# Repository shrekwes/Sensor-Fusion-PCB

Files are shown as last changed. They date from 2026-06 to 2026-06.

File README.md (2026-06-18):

# PyFusion — RP2040 Sensor Fusion Board

A compact, custom-fabricated two-layer sensor fusion PCB built around the Raspberry Pi RP2040. Integrates a 6-axis IMU, 3-axis magnetometer, and barometric pressure sensor on a single board — programmable natively in MicroPython.

---

## Hardware

| Component | Part | Interface | Address |
|---|---|---|---|
| Microcontroller | RP2040 (dual-core Cortex-M0+, 133MHz) | — | — |
| IMU | IAM-20680HV (6-axis accel + gyro) | I2C1 — GP2/GP3 | 0x68 |
| Magnetometer | IIS2MDCTR (3-axis AMR) | I2C0 — GP8/GP9 | 0x1E |
| Barometer | BMP581 (pressure + temperature) | SoftI2C — GP6/GP7 | 0x46 |
| Flash | W25Q128JVS (128Mbit QuadSPI) | QSPI | — |
| Crystal | ABM8-272-T3 (12MHz) | XIN/XOUT | — |
| Regulator | NCP1117-3.3 (5V → 3.3V LDO) | — | — |

---

## PCB Design

The board is a two-layer design captured in KiCad 9.0. Layout decisions were driven primarily by the sensitivity requirements of the three MEMS sensors.

### Layer Stack

- **Top layer** — signal routing and 3.3V power polygon pour
- **Bottom layer** — continuous ground plane for low-impedance return paths and shielding, with minimal routing tracks

### Sensor Placement

**IMU (IAM-20680HV)**
Placed on a mechanically stable region of the board, away from mounting holes and connectors. Requires a solid ground plane beneath it for noise reduction — copper fill is maintained under this device. The exposed ground pad is connected to the ground plane via multiple vias.

**Magnetometer (IIS2MDCTR)**
Highly sensitive to magnetic fields from nearby copper currents. Ground plane and copper pours are cleared on both layers in the region surrounding this device. High-current traces and switching components are kept at a distance.

**Barometer (BMP581)**
Isolated from large copper regions on both layers to prevent thermal gradients and mechanical stress from influencing pressure readings.

### Key Layout Decisions

**Decoupling** — All bypass capacitors placed within 1–2mm of their associated VDD pins, with short via stubs to the ground plane, in accordance with each sensor's datasheet.

**Crystal** — ABM8-272-T3 placed as close as practical to the RP2040 XIN/XOUT pins. Load capacitors are inline. A copper pour guard ring tied to GND prevents switching-noise coupling into the oscillator.

**USB differential pair** — USBDP/USBDM routed as a 90Ω differential pair (0.8mm track width, 0.15mm gap on a 1mm substrate) per the RP2040 hardware design guide.

**GPIO header** — 23 pins expose selected RP2040 GPIO signals for external interfacing via UART, SPI, or I2C, making the board extensible rather than a closed system.

**BOOTSEL and RESET** — dedicated push-buttons for bootloader entry and manual reset.

### KiCad Footprint Note

The IAM-20680HV KiCad footprint files were not available at the time of design. The **ICM-20602** footprint was used as a drop-in substitute — the two devices share an identical package and pin layout. The assembled board uses the IAM-20680HV component on the ICM-20602 footprint without modification.

### Design Verification

Before manufacture the following checks were completed in KiCad:
- Electrical Rules Check (ERC) — no unconnected pins or conflicting power nets
- Design Rules Check (DRC) — cleared against manufacturer minimums (trace width, clearance, via drill, annular ring)
- Footprint verification — each land pattern cross-checked against the manufacturer datasheet
- Gerber preview — layer stack-up, drill file, and copper patterns confirmed

---

## Firmware

All firmware is written in MicroPython and runs directly on the RP2040. The board was developed and flashed using Thonny IDE.

### File Overview

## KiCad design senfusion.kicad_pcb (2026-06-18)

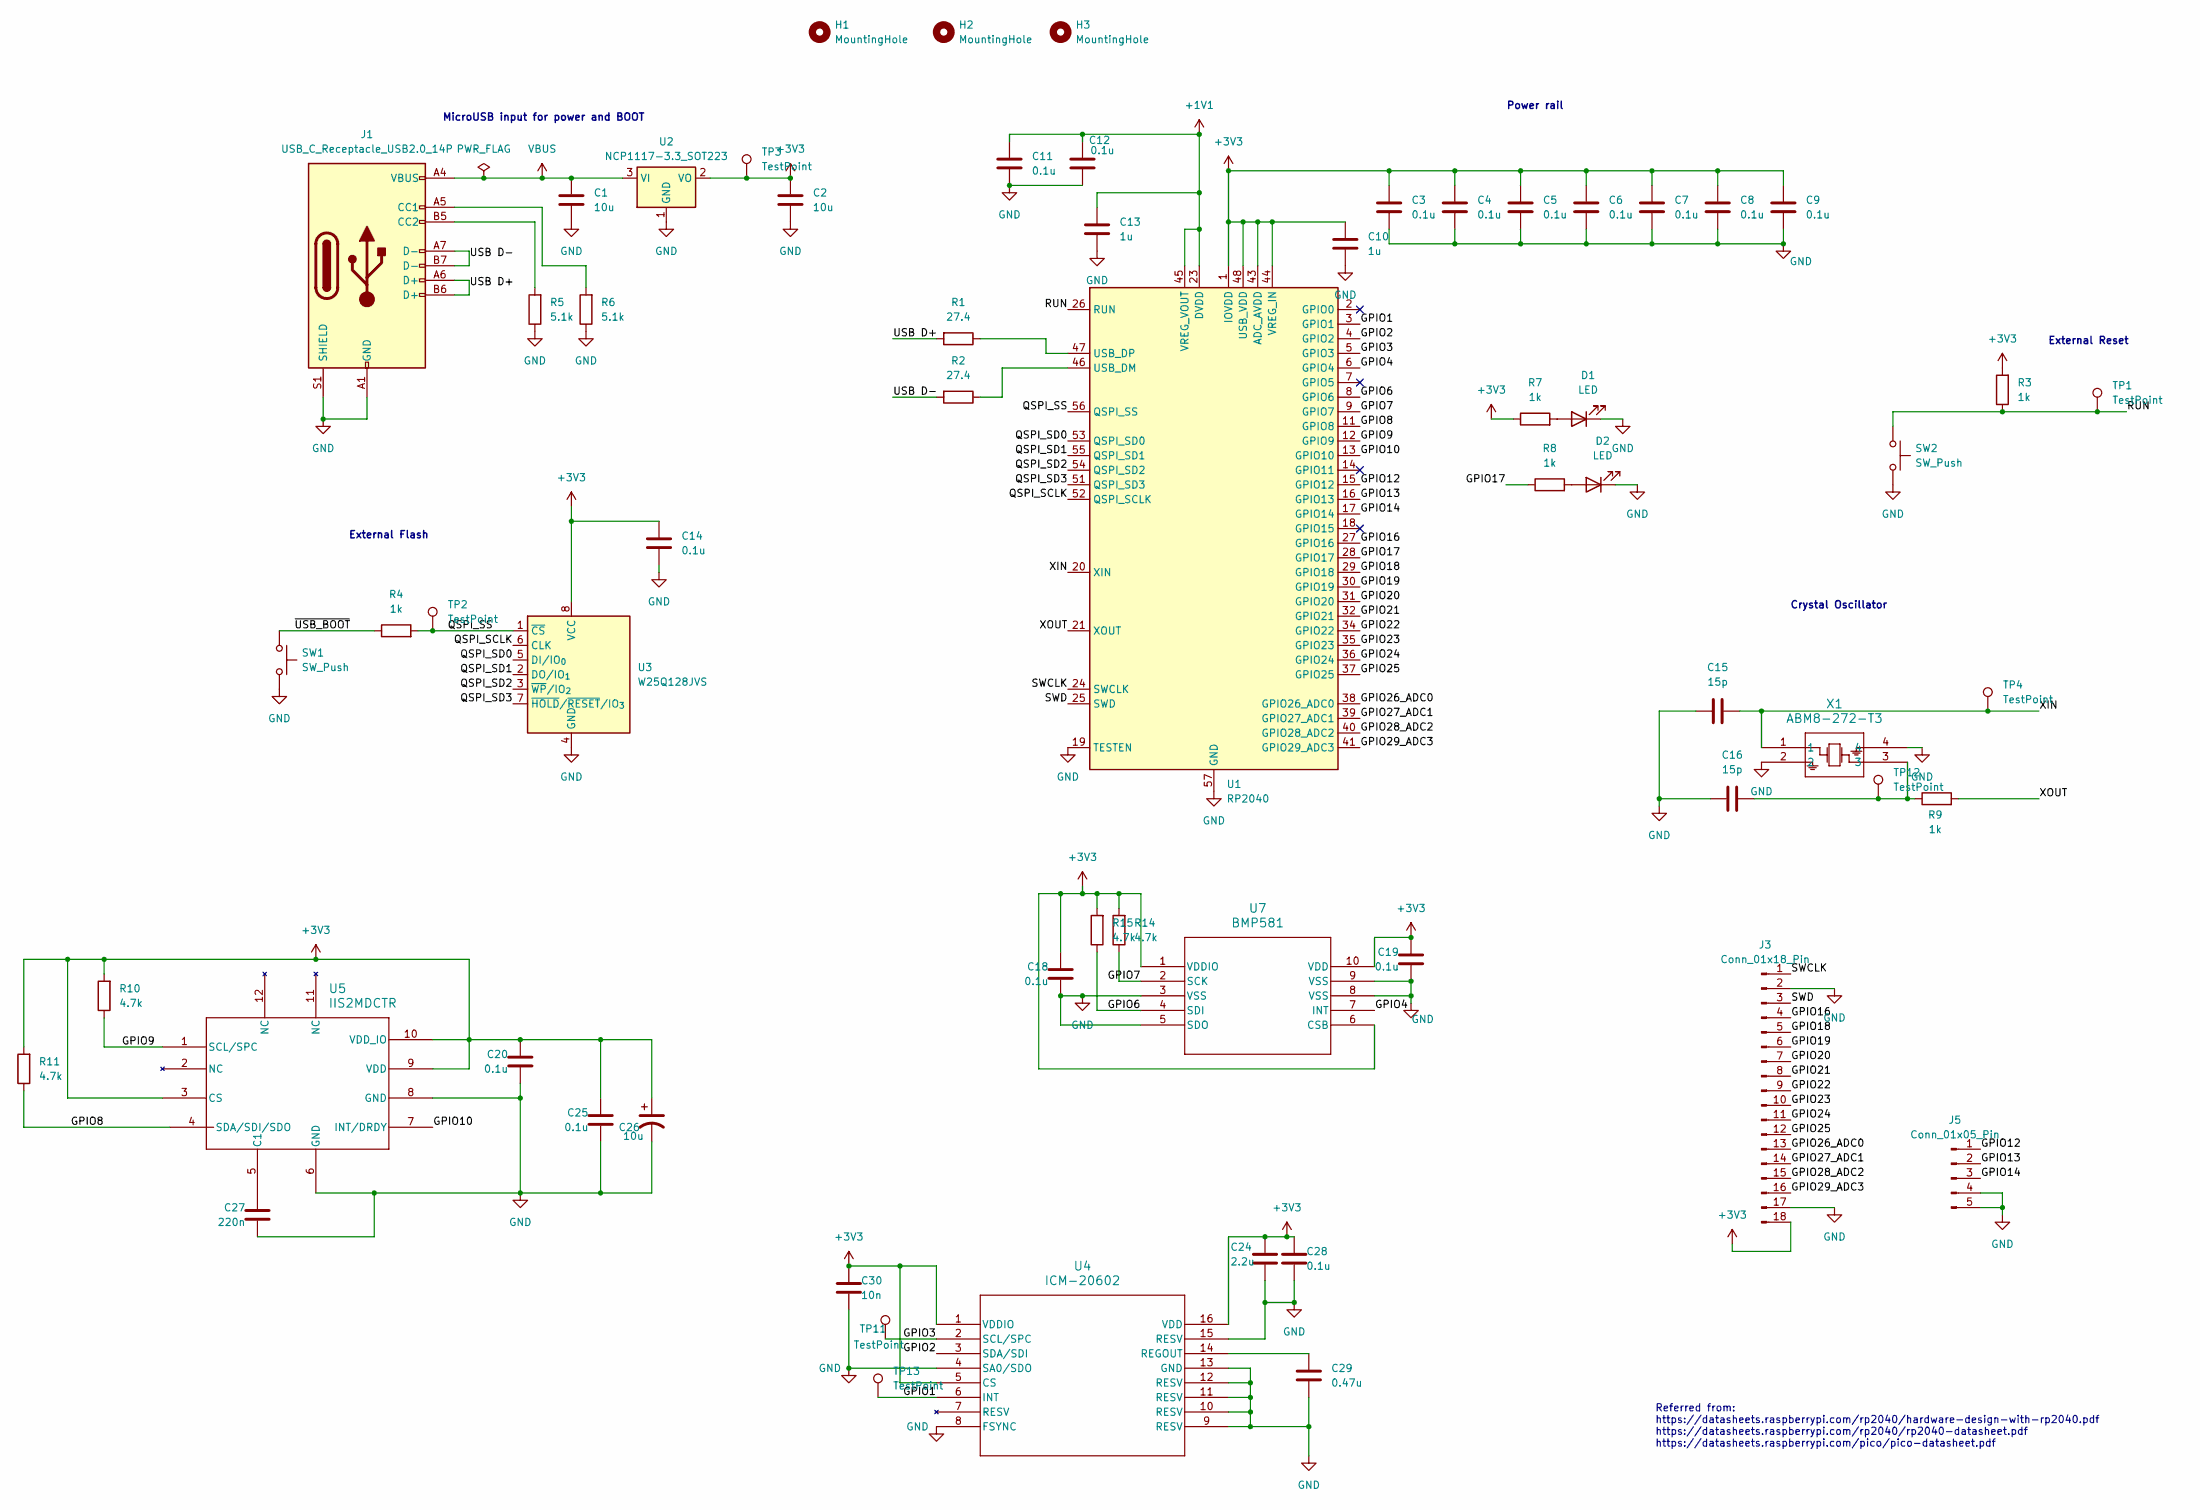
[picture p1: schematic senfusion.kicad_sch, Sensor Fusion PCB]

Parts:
C1, C2, C26: 10u; C_0603_1608Metric
C3, C4, C5, C6, C7, C8, C9, C11, C12, C14, C18, C19, C20, C25, C28: 0.1u; C_0402_1005Metric
C10, C13: 1u; C_0402_1005Metric
C15, C16: 15p; C_0402_1005Metric
C24: 2.2u; C_0402_1005Metric
C27: 220n; C_0402_1005Metric
C29: 0.47u; C_0402_1005Metric
C30: 10n; C_0402_1005Metric
D1, D2: LED; LED_0402_1005Metric
H1, H2, H3: MountingHole; MountingHole_2.2mm_M2
J1: USB_C_Receptacle_USB2.0_14P; USB_C_Receptacle_GCT_USB4105-xx-A_16P_TopMnt_Horizontal
J3: Conn_01x18_Pin; PinHeader_1x18_P2.54mm_Vertical
J5: Conn_01x05_Pin; PinHeader_1x05_P2.54mm_Vertical
R1, R2: 27.4; R_0402_1005Metric
R3, R4, R7, R8, R9: 1k; R_0402_1005Metric
R5, R6: 5.1k; R_0402_1005Metric
R10, R11, R14, R15: 4.7k; R_0402_1005Metric
SW1, SW2: SW_Push; SW_Push_1P1T_NO_CK_KMR2
TP1, TP2, TP3, TP4, TP11, TP12, TP13: TestPoint; TestPoint_Pad_D1.5mm
U1: RP2040; QFN-56-1EP_7x7mm_P0.4mm_EP3.2x3.2mm
U2: NCP1117-3.3_SOT223; SOT-223-3_TabPin2
U3: W25Q128JVS; SOIC-8_5.3x5.3mm_P1.27mm
U4: ICM-20602; LGA16_I62_IVS
U5: IIS2MDCTR; LGA-12_2X2X0P7_STM
U7: BMP581; QFN10_BMP581_BOS
X1: ABM8-272-T3; ABM8-272-T3_ABR

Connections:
+1V1: C11.1, C12.1, C13.1, U1.23 (DVDD), U1.45 (VREG_VOUT), U1.50 (DVDD)
+3V3: C2.1, C3.1, C4.1, C5.1, C6.1, C7.1, C8.1, C9.1, C10.1, C14.1, C18.1, C19.1, C20.1, C24.1, C25.1, C26.1, C28.1, C30.1, J3.18, R3.2, R7.1, R10.2, R11.2, R14.2, R15.2, TP3.1, U1.1 (IOVDD), U1.10 (IOVDD), U1.22 (IOVDD), U1.33 (IOVDD), U1.42 (IOVDD), U1.43 (ADC_AVDD), U1.44 (VREG_IN), U1.48 (USB_VDD), U1.49 (IOVDD), U2.2 (VO), U3.8 (VCC), U4.1 (VDDIO), U4.5 (CS), U4.16 (VDD), U5.3 (CS), U5.9 (VDD), U5.10 (VDD_IO), U7.1 (VDDIO), U7.6 (CSB), U7.10 (VDD)
/GPIO1: TP13.1, U1.3 (GPIO1), U4.6 (INT)
/GPIO2: U1.4 (GPIO2), U4.3 (SDA/SDI)
/GPIO3: TP11.1, U1.5 (GPIO3), U4.2 (SCL/SPC)
/GPIO4: U1.6 (GPIO4), U7.7 (INT)
/GPIO6: R15.1, U1.8 (GPIO6), U7.4 (SDI)
/GPIO7: R14.1, U1.9 (GPIO7), U7.2 (SCK)
/GPIO8: R11.1, U1.11 (GPIO8), U5.4 (SDA/SDI/SDO)
/GPIO9: R10.1, U1.12 (GPIO9), U5.1 (SCL/SPC)
/GPIO10: U1.13 (GPIO10), U5.7 (INT/DRDY)
/GPIO12: J5.1, U1.15 (GPIO12)
/GPIO13: J5.2, U1.16 (GPIO13)
/GPIO14: J5.3, U1.17 (GPIO14)
/GPIO16: J3.4, U1.27 (GPIO16)
/GPIO17: R8.1, U1.28 (GPIO17)
/GPIO18: J3.5, U1.29 (GPIO18)
/GPIO19: J3.6, U1.30 (GPIO19)
/GPIO20: J3.7, U1.31 (GPIO20)
/GPIO21: J3.8, U1.32 (GPIO21)
/GPIO22: J3.9, U1.34 (GPIO22)
/GPIO23: J3.10, U1.35 (GPIO23)
/GPIO24: J3.11, U1.36 (GPIO24)
/GPIO25: J3.12, U1.37 (GPIO25)
/GPIO26_ADC0: J3.13, U1.38 (GPIO26_ADC0)
/GPIO27_ADC1: J3.14, U1.39 (GPIO27_ADC1)
/GPIO28_ADC2: J3.15, U1.40 (GPIO28_ADC2)
/GPIO29_ADC3: J3.16, U1.41 (GPIO29_ADC3)
/QSPI_SCLK: U1.52 (QSPI_SCLK), U3.6 (CLK)
/QSPI_SD0: U1.53 (QSPI_SD0), U3.5 (DI/IO_{0})
/QSPI_SD1: U1.55 (QSPI_SD1), U3.2 (DO/IO_{1})
/QSPI_SD2: U1.54 (QSPI_SD2), U3.3 (~WP/IO_{2})
/QSPI_SD3: U1.51 (QSPI_SD3), U3.7 (~HOLD/~RESET/IO_{3})
/QSPI_SS: R4.2, TP2.1, U1.56 (QSPI_SS), U3.1 (~CS)
/RUN: R3.1, SW2.1, TP1.1, U1.26 (RUN); also elsewhere on the board
/SWCLK: J3.1, U1.24 (SWCLK)
/SWD: J3.3, U1.25 (SWD)
/USB D+: J1.A6 (D+), J1.B6 (D+), R1.2
/USB D-: J1.A7 (D-), J1.B7 (D-), R2.2
/XIN: C15.1, TP4.1, U1.20 (XIN), X1.1
/XOUT: R9.2, U1.21 (XOUT)
/~USB_BOOT: R4.1, SW1.1; also elsewhere on the board
GND: C1.2, C2.2, C3.2, C4.2, C5.2, C6.2, C7.2, C8.2, C9.2, C10.2, C11.2, C12.2, C13.2, C14.2, C15.2, C16.2, C18.2, C19.2, C20.2, C24.2, C25.2, C26.2, C27.2, C28.2, C29.2, C30.2, D1.1 (K), D2.1 (K), J1.A1 (GND), J1.A12 (GND), J1.B1 (GND), J1.B12 (GND), J1.S1 (SHIELD), J3.2, J3.17, J5.4, J5.5, R5.1, R6.1, SW1.2, SW2.2, U1.19 (TESTEN), U1.57 (GND), U2.1 (GND), U3.4 (GND), U4.4 (SA0/SDO), U4.8 (FSYNC), U4.9 (RESV), U4.10 (RESV), U4.11 (RESV), U4.12 (RESV), U4.13 (GND), U4.15 (RESV), U5.6 (GND), U5.8 (GND), U7.3 (VSS), U7.5 (SDO), U7.8 (VSS), U7.9 (VSS), X1.2, X1.4; also elsewhere on the board
unnamed: C16.1, R9.1, TP12.1, X1.3
unnamed: D1.2 (A), R7.2
unnamed: D2.2 (A), R8.2
unnamed: J1.A5 (CC1), R6.2
unnamed: J1.B5 (CC2), R5.2
unnamed: R2.1, U1.46 (USB_DM)
unnamed: R1.1, U1.47 (USB_DP)
unnamed: C29.1, U4.14 (REGOUT)
unnamed: C27.1, U5.5 (C1)
VBUS: C1.1, J1.A4 (VBUS), J1.A9 (VBUS), J1.B4 (VBUS), J1.B9 (VBUS), U2.3 (VI)

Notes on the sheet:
Referred from: https://datasheets.raspberrypi.com/rp2040/hardware-design-with-rp2040.pdf https://datasheets.raspberrypi.com/rp2040/rp2040-datasheet.pdf https://datasheets.raspberrypi.com/pico/pico-datasheet.pdf
Power rail
External Reset
External Flash
MicroUSB input for power and BOOT
Crystal Oscillator

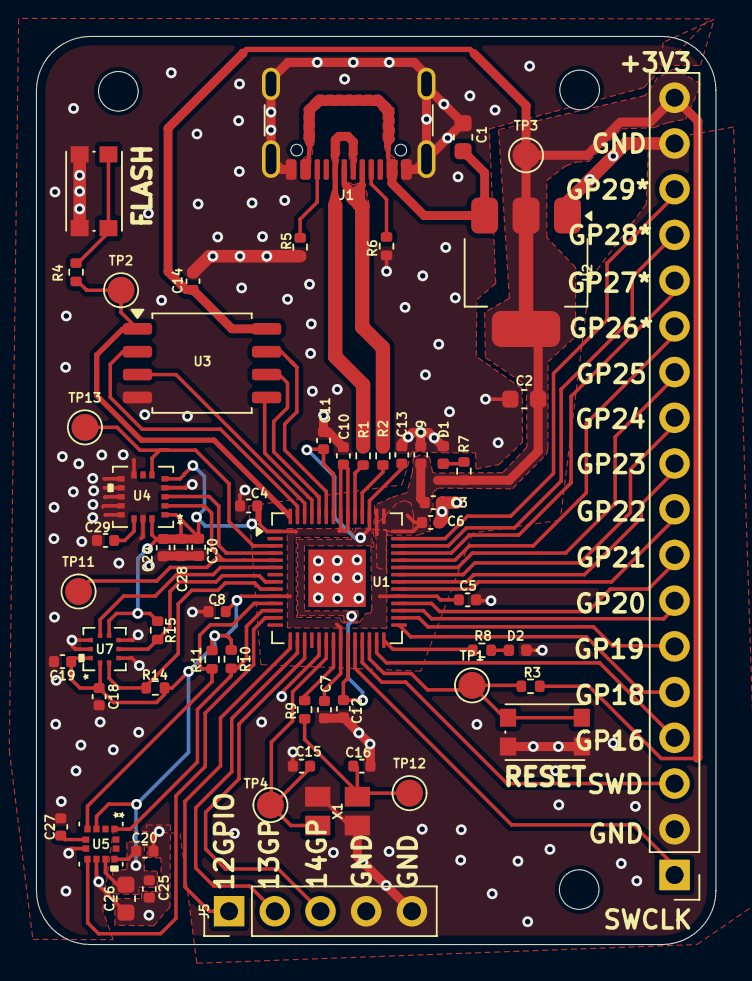
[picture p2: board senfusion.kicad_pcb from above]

Board: 2 copper layers, 37.7 x 50.5 mm, 63 parts (0 on the bottom side), 53 nets.

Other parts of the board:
FLASH: SW_Push; SW_Push_1P1T_NO_CK_KMR2
RESET: SW_Push; SW_Push_1P1T_NO_CK_KMR2

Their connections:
/RUN: RESET.1; also elsewhere on the board
/~USB_BOOT: FLASH.1; also elsewhere on the board
GND: FLASH.2, RESET.2; also elsewhere on the board
